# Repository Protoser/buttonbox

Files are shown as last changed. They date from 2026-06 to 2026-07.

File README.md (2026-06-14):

# Buttonbox

Custom USB button box built on an **ESP32-S3 N16R8** with a salvaged Ender 3 / CR-10 ST7920 display (128x64) and cheap mini push buttons. The device enumerates as a native USB HID gamepad and includes a companion PC app for live configuration, monitoring, media control, and button chord management.

## Build one / downloads

See the **[build guide](docs/BUILD.md)** for the bill of materials, the 3D-printed
case ([`3d_models/`](3d_models)), wiring/pinout, and assembly photos. You don't
have to compile anything — prebuilt `firmware.bin` and `ButtonboxCompanion.exe`
are on the Releases page.

## Hardware

- **MCU:** ESP32-S3 N16R8 DevKitC-1 (16 MB flash + 8 MB OPI PSRAM)
- **Display:** salvaged **Ender 3 / CR-10** "full graphic smart controller" — ST7920 128x64, software SPI
- **Buttons:** 15 cheap [mini push buttons](https://www.roboter-bausatz.de/p/schwarzer-mini-push-button) — 14 report as HID (10 always-on + 4 nav), plus 1 menu/mode toggle
- **USB:** Native TinyUSB CDC + gamepad HID

## Project structure

```
platformio.ini        PlatformIO config (ESP32-S3, Arduino framework)
src/                  ESP32 firmware source code
  main.cpp            Entry point — init in setup(), tick in loop()
  config.h            Pin map and constants
  settings.h/.cpp     NVS-persisted device settings
  buttons.h/.cpp      Debounced button input handling
  hid.h/.cpp          USB HID gamepad report generation
  chords.h/.cpp       Multi-button combos -> output keypresses
  display.h/.cpp      ST7920 LCD drawing (U8g2)
  ui.h/.cpp           On-screen menu pages, navigation and rendering
  hostlink.h/.cpp     Serial protocol: PC telemetry + config commands
  pcstats.h/.cpp      PC stats display page (CPU/RAM/GPU/temps)
  shelly.h/.cpp       Shelly smart switch integration
  stopwatch.h/.cpp    Lap timer utility

host/                 Windows companion app (Python / PySide6)
  app.py              System-tray GUI with Monitor, Device, and Chords tabs
  link.py             Background serial thread — discovery, telemetry, auto-reconnect
  sensors.py          Hardware sensor reads via psutil + LibreHardwareMonitor
  media.py            Now-playing title + media controls (Windows media session)
  secrets_store.py    Encrypted local store for the Shelly password (Windows DPAPI)
  pcstats.py          Headless CLI fallback (no GUI), streams stats only
  companion.spec      PyInstaller build spec
  build.bat           One-shot build script -> dist/ButtonboxCompanion.exe

include/              Shared project header files
lib/                  Private PlatformIO libraries
test/                 PlatformIO test runner directory
```

## Quick start — firmware

Requires [PlatformIO](https://platformio.org).

```bash
pio run -t upload    # flash to device
pio monitor          # serial console at 115200 baud
```

The build requires `espressif32` platform and the U8g2 library (pulled automatically via PlatformIO lib_deps).

## Quick start — companion app

```powershell
cd host
pip install PySide6 pyserial psutil
pip install winrt-Windows.Media.Control winrt-Windows.Foundation   # optional: Music page
pythonw app.py       # tray app (no console window)
```

Prefer not to install Python? Grab the prebuilt **`ButtonboxCompanion.exe`** from the Releases page.

### Prerequisites for full sensor support

GPU load/temp and CPU temperature require [LibreHardwareMonitor](https://github.com/LibreHardwareMonitor/LibreHardwareMonitor). Download the release zip, copy all `.dll` files into `host/`, and run the app as Administrator.

### Build standalone executable

```powershell
cd host
build.bat            # outputs dist/ButtonboxCompanion.exe
```

## Features

- **Native USB gamepad** — all 14 buttons report as HID keys, works in any game or app without drivers
- **On-screen menu** — navigate settings with the 4 multiplexed buttons and LCD display
- **Button chords** — combine 2+ physical buttons into a single output keypress (configured via PC app)
- **PC telemetry overlay** — live CPU/RAM/GPU load, temperatures, power, and VRAM displayed on the box screen
- **Music app** — shows the current track (artist / title, Cyrillic-capable) from the Windows media session and runs play/pause, next, and previous from the box (companion app required)
- **Device configuration** — rotate display, set idle blank timeout, boot screen selection, chord editing, and more — all persisted in NVS flash
- **Auto-reconnect** — companion app reconnects automatically if the USB cable is unplugged/replugged

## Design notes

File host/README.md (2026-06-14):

# Buttonbox Companion (PC app)

A system-tray app that streams PC stats to the buttonbox **and** reads/edits the
device's settings and chords live over its USB serial link. Starts minimized to
the tray and **auto-reconnects** whenever the box is unplugged/replugged.

```
host/
  app.py          the companion app (tray + Monitor / Device / Chords tabs)
  link.py         background serial thread: discovery, telemetry, commands, auto-reconnect
  sensors.py      sensor reading (psutil + LibreHardwareMonitor)
  media.py        now-playing title + transport control (Windows media session)
  pcstats.py      headless CLI fallback (no GUI), shares sensors.py
  companion.spec  PyInstaller build -> standalone .exe
  build.bat       one-shot build script
```

## Run from source

```powershell
pip install PySide6 pyserial psutil
pip install winrt-Windows.Media.Control winrt-Windows.Foundation   # Music page
python app.py            # tray app (use pythonw app.py for no console flash)
```

The two `winrt-*` packages power the **Music** page (now-playing title +
transport control) and ship prebuilt wheels (incl. Python 3.13). They're
optional — without them everything else still runs and Music just shows "Nothing
playing". (The older all-in-one `winsdk` package also works but has no 3.13
wheel, so it tries to compile from source and fails — use the `winrt-*` packages.)

It appears in the system tray (blue "BB" icon). **Left-click** the tray icon to
open the window, **right-click** for the menu (Show / Start at login / Flash
device / Quit). Closing the window hides it back to the tray.

- **Monitor** tab — connection status + live CPU/RAM/GPU/temp bars.
- **Device** tab — Rotate, grid Labels, Idle-blank, Chord window, Boot screen,
  and which PC stats the box shows. Changing any control writes it to the box and
  it persists in the box's flash. There's also a **Flash Mode** button (handy for
  firmware uploads).
- **Chords** tab — see/add/delete button chords (pick 2+ member buttons + an
  output button); changes apply on the box immediately.

The box also has a **Music** page (in its app launcher). The companion streams
the current media-session title to it and relays the box's prev / play-pause /
next button presses back to whatever is playing (Spotify, browser/YouTube, …) —
the same targets the keyboard media keys hit. Needs the `winrt-*` packages (see above).

## Temperatures (LibreHardwareMonitor)

CPU load + RAM need nothing extra. GPU load/temp and **CPU temp** need a sensor
source:

1. `pip install pythonnet`, then copy **all `.dll` files** from the
   LibreHardwareMonitor release zip into this `host/` folder
   (`LibreHardwareMonitorLib.dll` **and** its siblings `System.Memory.dll`,
   `System.Buffers.dll`, `System.Runtime.CompilerServices.Unsafe.dll`,
   `System.Numerics.Vectors.dll`, `System.Threading.Tasks.Extensions.dll`,
   `HidSharp.dll`). The app resolves them from this folder automatically.
2. **Run the app as Administrator** — CPU temperature comes from MSR/SuperIO,
   which needs the kernel sensor driver. Without admin you'll still get CPU/RAM
   and GPU load/temp, just not CPU temp.

## Build a standalone .exe

Put the LHM DLLs in `host/` first (they get bundled), then:

```powershell
build.bat            # or:  py -m PyInstaller --noconfirm companion.spec
```

Output: `dist\ButtonboxCompanion.exe` — runs without Python. Run it as admin for
temps.

## Start at login

Toggle **Start at login** in the tray menu — it adds/removes an entry under
`HKCU\…\CurrentVersion\Run` pointing at the exe (or `pythonw app.py` when run
from source), so the app launches minimized to the tray on sign-in.

## Headless fallback

`python pcstats.py` just streams stats (no GUI, no config), also auto-reconnecting.

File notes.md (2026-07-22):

## What's new since v2.3

### Clock app

- **New Clock app in the launcher** — a full-screen wall clock driven by the box's synced time (NTP over WiFi, or pushed from the PC companion; no RTC needed).
- **Analog face** inspired by a De Bethune dial: hollow **lance hands** (shaft → hollow lozenge → pointed tip) for the hour and minute, a thin sweeping second hand, and a full ring of **12 numerals** with an hour pip on the rim.
- **Digital style** as an alternative — big `HH:MM` with optional seconds and AM/PM.
- **Weekday + date** line along the bottom.
- The face uses the whole panel (no header bar) and keeps the display awake so the seconds hand keeps ticking.

### Customizing the clock

- **On the box → open Clock → Select (►)** opens a per-clock settings page. Toggle each option with Select:
  - **Style** — Analog / Digital
  - **Seconds** — show the seconds hand (or digital seconds)
  - **Numerals** — all-12 numerals vs. a plain tick ring
  - **Date** — show the weekday/date line
  - **Hour fmt** — 24h / 12h
- Settings persist across reboots.

### Fixes

- Fixed a launcher bug where adding an app could write one entry past the app-order list and corrupt adjacent settings.
- Companion app list and Boot-screen dropdown now include the **Volume** and **Clock** apps, keeping them index-aligned with the firmware.

## Install

- **Firmware:** flash `firmware.bin` to the ESP32-S3 (PlatformIO, or the on-device Flash Mode + esptool). The Clock app appears in the launcher; open it and press Select to customize.
- **Companion (Windows only):** run `ButtonboxCompanion.exe`.

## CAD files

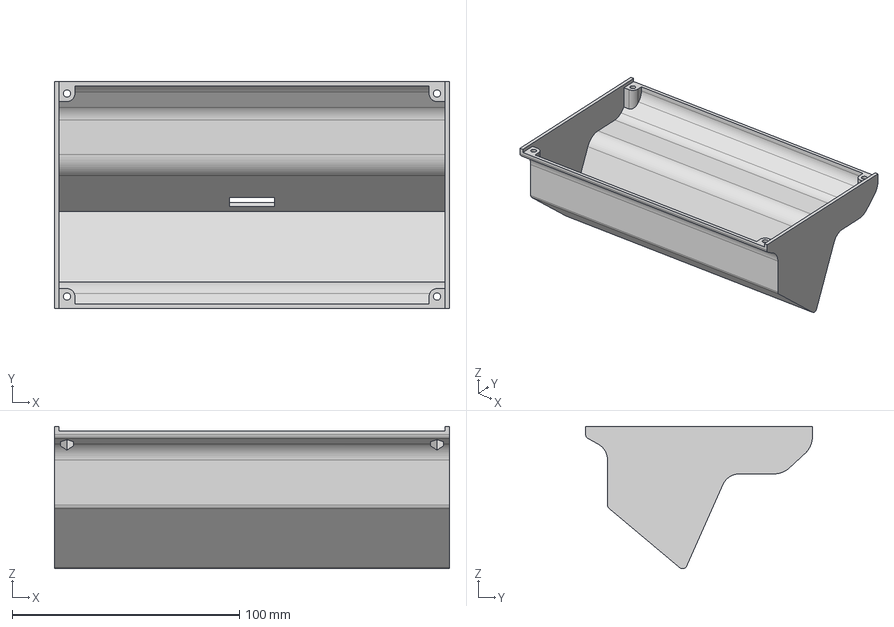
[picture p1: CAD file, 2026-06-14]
3d_models/Case.step
174.0 x 99.9 x 62.7 mm

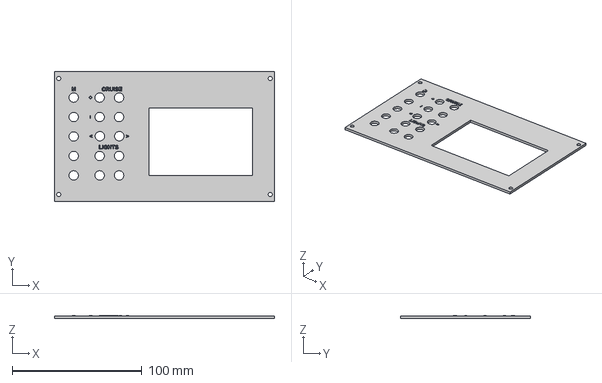
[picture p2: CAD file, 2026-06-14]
3d_models/Lid.step
169.6 x 100.0 x 2.40 mm

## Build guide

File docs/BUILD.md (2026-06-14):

# Build guide

This button box reuses the graphic LCD from an **old Ender 3 / CR‑10** (the stock
"full graphic smart controller" — a 128×64 **ST7920** panel) plus a handful of
**cheap mini push buttons**, driven by an ESP32‑S3. It enumerates as a plain USB
gamepad, so it needs no drivers, and a small Windows companion app adds live PC
stats, media control, and configuration.

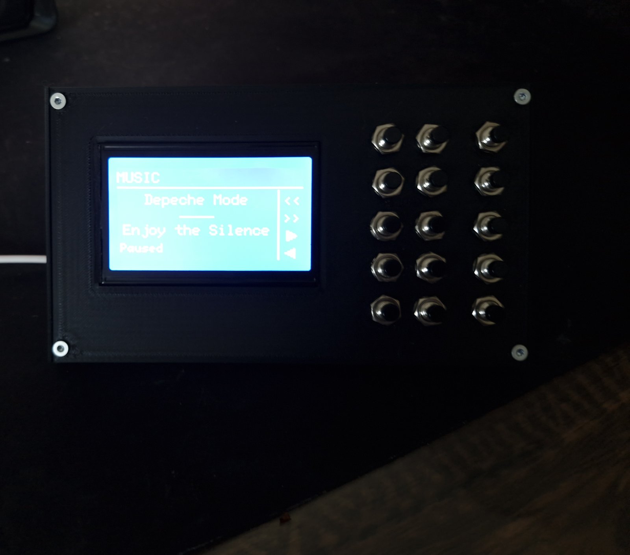
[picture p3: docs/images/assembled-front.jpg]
Assembled button box showing the Music page


## You don't have to build anything from source

Prebuilt artifacts are on the project's **Releases** page — you can skip the
toolchains entirely:

- **`firmware.bin`** — flash it straight to the ESP32‑S3 (see [Flashing](#flashing-the-firmware)).
  No PlatformIO / Arduino install needed.
- **`ButtonboxCompanion.exe`** — the Windows companion app. Just run it; no Python needed.

Building from source is only necessary if you want to change the firmware or the app.

## Bill of materials

| Qty | Part | Notes |
|----:|---|---|
| 1 | ESP32‑S3 **N16R8 DevKitC‑1** | 16 MB flash / 8 MB PSRAM. Any ESP32‑S3 devkit with native USB works. |
| 1 | 128×64 **ST7920** "12864" graphic LCD | The **Ender 3 / CR‑10 stock display** (RepRapDiscount full graphic smart controller). Salvage one, or buy a 12864 module. |
| 15 | Mini push buttons | e.g. [roboter‑bausatz mini push button](https://www.roboter-bausatz.de/p/schwarzer-mini-push-button). |
| — | Hook‑up / Dupont wire | For the button and display wiring. |
| 1 | USB‑C cable (data) | To the ESP32‑S3. |
| 4 | M3 screws | Hold the lid to the case (corners). |
| — | 3D‑printed **Case** + **Lid** | See below. |

The 15 buttons break down as **10 main** + **4 nav** + **1 menu/mode** button.

> **ESP32-S3 board notes:**
> - Use the port labeled **USB** (the native USB), **not COM** (the UART bridge) — the
>   box only enumerates as a USB gamepad over the native USB port.
> - On **clone** boards, bridge the **IN-OUT** solder pads so the USB port's 5V is
>   routed to the board's **5V** pin — that's what powers the screen. (Genuine
>   Espressif boards already have this connected.)

## 3D‑printed parts

STEP files are in [`3d_models/`](../3d_models):

- [Case.step](../3d_models/Case.step) — the body that covers the wiring
- [Lid.step](../3d_models/Lid.step) — the front cover containing the screen and buttons

### Two mounting orientations

The box works **either way up** — display‑left / buttons‑right, or
display‑right / buttons‑left — so you can mount it to suit your desk. The
firmware's **Rotate** setting flips the screen 180° *and* moves the on‑screen
button hints to the matching side. Set it once to match how you mounted it:

- on‑device: **Menu → Settings → Rotate**, or
- in the companion's **Device** tab → *Rotate*.

### Removing the embossed text

The part has text embossed on it. To print without it, remove it in your slicer:
import the STEP, **split it into parts/objects**, select the **text body**, and
delete it before slicing.

- PrusaSlicer / Bambu Studio / OrcaSlicer: right‑click the object → *Split to objects/parts*
- Cura: *Split model into parts*

The rest of the part is unaffected.

## Preparing the salvaged screen

These 12864 panels come as a full controller board with a **rotary encoder**, a
**buzzer/speaker** (the "BELL +" pad visible in the soldered photo), an SD slot and
a reset button. This build uses only the LCD, so **desolder the rotary encoder and
the buzzer** — they're unused and the encoder sticks out the front, so removing it
lets the panel sit flush in the lid.

I went the separate‑push‑button route on purpose: the encoder on my salvaged
screen was **dead**, and that's common — these displays often sit in a drawer for
years after a printer upgrade, and the encoder (or its solder joints / contacts)
degrades. Driving the ST7920 LCD directly and adding cheap new buttons sidesteps a
part that's likely broken anyway.

## Wiring / pinout

Every button is wired the same trivial way: **one leg to a GPIO, the other leg to
GND**. The firmware enables the ESP32's internal pull‑ups, so **no resistors are
needed**. All the button grounds can share a single daisy‑chained GND wire (see
the soldered photo below).

### Display (ST7920, software SPI)

| ESP32‑S3 | Display pin |
|---|---|
| GPIO **17** | **Clock** (ST7920 E) |
| GPIO **18** | **Data** (ST7920 R/W / MOSI) |
| GPIO **21** | **Chip Select** (ST7920 RS) |
| **5V** | **5V** |
| **GND** | **Ground** |

On the Ender 3 / CR‑10 12864 these signals come out on the **EXP3** ribbon and the
panel PCB is labeled (E / RW / RS). It runs in ST7920 *serial* mode (the PSB pin
tied low — already handled on the RepRapDiscount board).

The diagram below — an **ST7920-based Ender 3 display** (EXP3 connector) — labels
the lines by function, which makes wiring obvious:

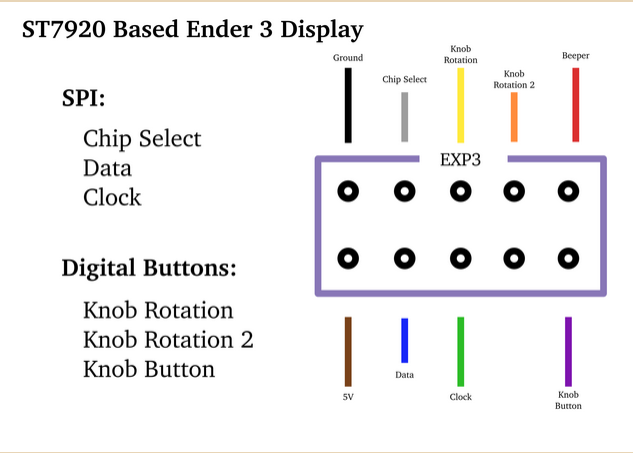
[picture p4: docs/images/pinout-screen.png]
ST7920-based Ender 3 display: EXP3 connector pinout


Connect **Ground** and **5V** to the ESP's GND/5V, and the three SPI lines to the
GPIOs in the table above: **Clock -> GPIO 17**, **Data -> GPIO 18**,
**Chip Select -> GPIO 21**. The remaining pins (Knob Rotation x2, Knob Button,
Beeper) drove the original encoder and buzzer and aren't used here.

*Connector pinout diagram from [maddie.info](https://maddie.info/hardware/2023/07/01/ender3-exp3-pinout.html).*

### Buttons

| ESP32‑S3 GPIO | Role |
|---|---|
| **2** | Menu / Mode button (not a HID button) |
| **1** | Nav — Up |
| **5** | Nav — Down |
| **6** | Nav — Select |
| **4** | Nav — Back |
| **7, 8, 9, 10, 11, 12, 13, 14, 15, 16** | Main HID buttons 1–10 |

The 4 nav buttons double as HID buttons 11–14 in normal mode; the **menu/mode**
button switches those four between gamepad buttons and on‑screen menu navigation.
The full pin map lives in [`src/config.h`](../src/config.h) if you want to rewire.

## Assembly

| Jumpered (test first) | Soldered (tidy) |
|---|---|
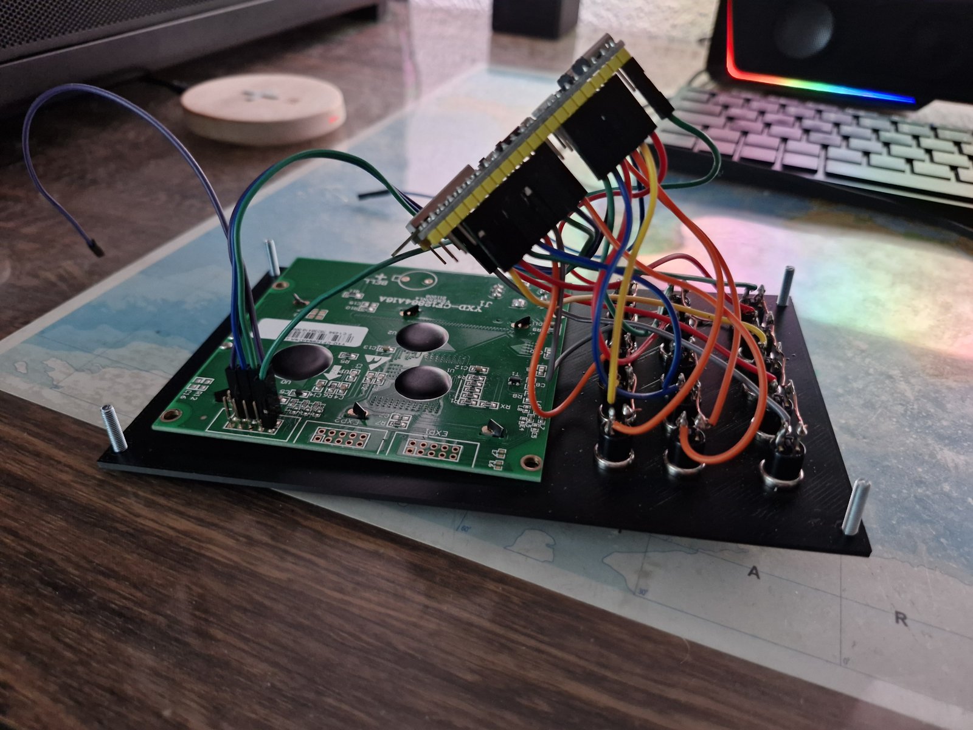
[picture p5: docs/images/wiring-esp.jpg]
ESP wired to buttons and display
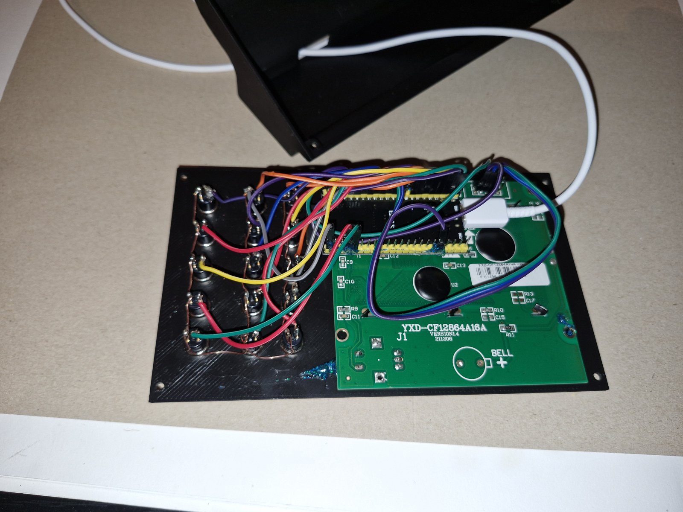
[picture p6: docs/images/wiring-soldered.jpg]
Buttons soldered with a shared ground chain
|  |  |

1. Print both parts (remove the embossed text first if you want it gone).
2. Desolder the encoder + buzzer from the screen (see above), then mount the 15 push buttons and the LCD into the **Lid** (the front).
3. Wire each button: signal leg → its GPIO (table above), other leg → the shared GND chain.
4. Wire the display's five lines to the ESP (table above).
5. Set the ESP into the **Case** (the back body), join it to the Lid, screw the corners, and plug in USB.

Tip: build the messy jumper‑wire version first and confirm every button and the
screen work, *then* solder it tidy.

## Flashing the firmware

**Prebuilt (recommended):** download `firmware.bin` (a full, merged flash image)
from the Releases page and write it at offset **0x0**:

- Browser flasher — open <https://espressif.github.io/esptool-js/>, connect, set
  offset `0x0`, choose `firmware.bin`, **Program**.
- Or esptool — `esptool --chip esp32s3 write_flash 0x0 firmware.bin`

To put a running box into download mode: use the companion's **Flash Mode** button,
or hold **BOOT** on the devkit while tapping **RESET**, then release BOOT.

**From source:** with [PlatformIO](https://platformio.org) installed, `pio run -t upload`
(see the main [README](../README.md)).

## Companion app (optional)

The Windows companion streams PC stats to the box, drives the **Music** page
(now‑playing title + transport control), and edits the box's settings and chords
live. Use the prebuilt `ButtonboxCompanion.exe`, or run it from source — see
[`host/README.md`](../host/README.md).

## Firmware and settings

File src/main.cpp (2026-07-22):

// ============================================================================
//  ESP32-S3 buttonbox  —  15 buttons + CR-10 (ST7920) display
//
//  Native NKRO USB HID keyboard + an on-screen menu UI. Modules:
//    config    pin map / counts            buttons   debounced inputs
//    display   the ST7920 panel            hid       key output dispatch
//    settings  NVS-persisted options       keyboard  NKRO USB keyboard
//    chords    2+ button combos -> output  ui        pages / nav / rendering
//  This file just wires them together: init in setup(), tick in loop().
// ============================================================================

#include <Arduino.h>
#include "soc/soc.h"            // REG_CLR_BIT
#include "soc/rtc_cntl_reg.h"   // RTC_CNTL_OPTION1_REG, RTC_CNTL_FORCE_DOWNLOAD_BOOT
#include "settings.h"
#include "buttons.h"
#include "hid.h"
#include "chords.h"
#include "hostlink.h"
#include "shelly.h"
#include "wled.h"
#include "clock.h"
#include "ui.h"

#if !defined(ARDUINO_USB_MODE) || ARDUINO_USB_MODE != 0
#error "Set -DARDUINO_USB_MODE=0 in platformio.ini so the box enumerates as a native USB keyboard."
#endif

void setup() {
  // Clear the force-download flag so a normal reset never re-enters flash mode.
  REG_CLR_BIT(RTC_CNTL_OPTION1_REG, RTC_CNTL_FORCE_DOWNLOAD_BOOT);

  loadSettings();
  chordsLoad();
  shellyBegin();
  wledBegin();
  clockBegin();
  uiBegin();
  // buttonsBegin() runs AFTER uiBegin() on purpose: displayBegin() brings up hardware
  // SPI, whose ESP32 init grabs the bus's default MISO pad (GPIO 13) — which is HID
  // button 7. Claiming the button pins last re-owns GPIO 13 as INPUT_PULLUP so it
  // stops floating and machine-gunning phantom presses. See display.cpp.
  buttonsBegin();
  hidBegin();
  Serial.begin(115200);
  uiNoteActivity(millis());
}

void loop() {
  uint32_t now = millis();

  buttonsUpdate(now);
  hostlinkUpdate(now);            // drain serial: PC telemetry + config commands
  clockUpdate(now);               // bring up NTP once WiFi is associated
  if (buttonsAnyEdge())         uiNoteActivity(now);
  uiHandleMenuButton(now);        // tap = launcher/resume, hold = quick-switch app

  // The brightness overlay (opened by a chord) is modal: while it's up it owns the
  // nav buttons on whatever page is showing, so it runs before normal page input.
  if (!uiHandleBrightness(now)) {
    // On non-Buttons pages the UI first claims the buttons it needs (the nav
    // buttons, or all buttons on the capture/test pages) by suppressing them.
    if (uiPage() != PAGE_BUTTONS) uiHandlePageInput();
  }
  // The chord/HID engine then runs on EVERY page: any button not claimed by the
  // UI stays a live key (so the non-nav buttons work everywhere).
  updateChords(now);

  if (uiPage() == PAGE_TIMER)   uiHandleTimerLap(now);
  uiTickCountdown(now);            // countdown timer: expiry pop-up (any page) + hold gestures
  uiHandleWledBright(now);         // self-gating; handles hold-to-scroll + release flush
  // The display renders on its own task pinned to core 0 (started in uiBegin) so the
  // slow ST7920 flush never blocks button sampling here on core 1.
}

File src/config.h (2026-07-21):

#pragma once
#include <Arduino.h>

// ============================================================================
//  Pin map  —  ESP32-S3 N16R8 DevKitC-1
//  Avoided: 19/20 (native USB), 26-32 (flash), 33-37 (octal PSRAM),
//           0/3/45/46 (strapping).
// ============================================================================

// ---- CR-10 display (ST7920 128x64, software SPI) ----
static const uint8_t LCD_CLOCK_PIN = 17;  // ST7920 E   (clock)
static const uint8_t LCD_DATA_PIN  = 18;  // ST7920 R/W (data / MOSI)
static const uint8_t LCD_CS_PIN    = 21;  // ST7920 RS  (chip select)

// ---- Backlight dimming ----
// GPIO -> series resistor -> backlight LED. Driven by LEDC PWM (see display.cpp);
// duty sets brightness. Low current, so no MOSFET — the pin sinks/sources it direct.
static const uint8_t LCD_BACKLIGHT_PIN = 38;

// ---- Mode toggle ("menu" button) ----
// The cluster button wired to GPIO 2 (the one you use as the menu button).
// Switches the 4 nav buttons between HID buttons (NORMAL) and on-screen
// menu navigation (MENU). It is NOT reported as a HID button itself.
static const uint8_t MODE_TOGGLE_PIN = 2;

// ---- Always-on HID buttons ----
// Each wires GPIO -> button -> GND (internal pull-ups, no resistors needed).
// The 10 non-cluster buttons; no special function, numbering doesn't matter.
// HID button index is assigned in array order, starting at 0.
static const uint8_t ALWAYS_BUTTON_PINS[] = {7, 8, 9, 10, 11, 12, 13, 14, 15, 16};

// ---- The 4 menu/nav buttons ----
// The other four cluster buttons, listed physical TOP -> BOTTOM.
// NORMAL mode: HID buttons (indices continue after the always-on set: 10..13).
// MENU mode:   UP, DOWN, SELECT, BACK  (in this order — rearrange to taste).
static const uint8_t NAV_BUTTON_PINS[] = {1, 5, 6, 4};

static constexpr uint8_t NUM_ALWAYS = sizeof(ALWAYS_BUTTON_PINS) / sizeof(ALWAYS_BUTTON_PINS[0]);
static constexpr uint8_t NUM_NAV    = sizeof(NAV_BUTTON_PINS)    / sizeof(NAV_BUTTON_PINS[0]);
static constexpr uint8_t NUM_HID    = NUM_ALWAYS + NUM_NAV;   // 14 physical buttons

// Menu navigation actions, in NAV_BUTTON_PINS order.
enum NavAction : uint8_t { NAV_UP = 0, NAV_DOWN = 1, NAV_SELECT = 2, NAV_BACK = 3 };

// Lockout debounce window (see buttons.cpp): a press registers the instant the
// contact closes, then any further edge is ignored for this long. So it both
// catches a short click and collapses contact bounce / rapid retriggers into one
// press. Set it a bit above the switch's worst-case bounce (~10-20 ms for cheap
// tactile/arcade buttons). It's also the minimum gap between two distinct presses.
static const uint16_t DEBOUNCE_MS = 50;

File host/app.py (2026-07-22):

"""Buttonbox companion — system-tray app that streams PC stats to the box and
reads/edits its settings and chords live. Starts minimized to the tray.

The window is a left-sidebar settings app: a short list of focused panes
(Monitor / Display / Apps / Chords / Network / Device) rather than a few
overloaded tabs, so each screen stays small and single-purpose. A persistent
header shows the connection state from every pane.

Run:   python app.py        (or pythonw app.py for no console)
"""
import os
import sys

from PySide6.QtCore import Qt, QTimer, QUrl, Signal
from PySide6.QtGui import QAction, QColor, QFont, QIcon, QPainter, QPalette, QPixmap
from PySide6.QtWebSockets import QWebSocket
from PySide6.QtWidgets import (
    QApplication, QCheckBox, QComboBox, QFormLayout, QFrame, QGridLayout, QGroupBox,
    QHBoxLayout, QLabel, QLineEdit, QListWidget, QListWidgetItem, QMainWindow, QMenu,
    QProgressBar, QPushButton, QScrollArea, QStackedWidget, QSystemTrayIcon, QTabWidget,
    QVBoxLayout, QWidget,
)

import mcdu as mcdu_mod
import secrets_store
from link import DeviceLink

MCDU_WS_URL = "ws://localhost:8380/interfaces/v1/mcdu"   # FlyByWire SimBridge remote MCDU

# ---- constants mirrored from the firmware (config.h / settings) ----
NUM_HID = 14            # physical buttons, shown 1..14
OUT_MIN, OUT_MAX = 14, 31     # chord outputs (shown 15..32)
OUT_BRIGHT = 32         # special chord output: open the backlight-brightness overlay (mirror chords.h CHORD_OUT_BRIGHT)
OUT_VOLUME = 33         # special chord output: open the volume mixer page (mirror chords.h CHORD_OUT_VOLUME)
TOGGLE_BIT = NUM_HID    # chord-member bit for the menu/toggle button (mirror chords.h CHORD_MEMBER_TOGGLE)
MAX_CHORDS = 18
IDLE_OPTS  = [(0, "Off"), (30, "30 s"), (120, "2 min")]
CHORD_OPTS = [30, 40, 60, 80]
BRIGHT_OPTS  = [(v, f"{v}%") for v in (10, 25, 40, 55, 70, 85, 100)]   # normal backlight brightness
IDLEBR_OPTS  = [(0, "Off"), (10, "10%"), (20, "20%"), (40, "40%")]     # dimmed backlight brightness
DIM_OPTS     = [(0, "Off"), (10, "10 s"), (30, "30 s"), (60, "60 s")]  # auto-dim delay
BOOT_OPTS  = [(0, "Apps launcher"), (1, "Buttons"), (2, "Stopwatch"), (3, "PC"), (4, "Shelly"),
              (5, "Music"), (6, "Menu"), (7, "WLED"), (8, "BeamNG"), (9, "Flight"), (10, "MCDU"),
              (11, "Timer"), (12, "Volume"), (13, "Clock")]
APP_NAMES  = ["Buttons", "Stopwatch", "PC", "Shelly", "Music", "Menu", "WLED", "BeamNG", "Flight",
              "MCDU", "Timer", "Volume", "Clock"]  # mirror ui.cpp APPS index order
MENU_APP   = APP_NAMES.index("Menu")   # never hideable
PCSTAT_BITS = [("CPU", 0), ("RAM", 1), ("GPU", 2), ("CPU Temp", 3), ("GPU Temp", 4),
               ("VRAM", 5), ("CPU Power", 6), ("GPU Power", 7)]
PCSTAT_MAX = 5      # box shows up to 5 at once
# (wire key, label, unit, bar min, bar max)
STAT_ROWS = [("cpu", "CPU", "%",   0, 100), ("ram", "RAM", "%",   0, 100), ("gpu", "GPU", "%", 0, 100),
             ("ct", "CPU Temp", "°C", 30, 100), ("gt", "GPU Temp", "°C", 30, 100),
             ("vr", "VRAM", "%", 0, 100), ("cp", "CPU Power", "W", 0, 250), ("gp", "GPU Power", "W", 0, 450)]

# Keyboard bindings (Keys pane). Each output (0..13 physical, 14..31 chord outputs) maps to a
# modifier mask + one HID usage (Keyboard/Keypad page 0x07; 0 = unbound). F13–F24 lead the list:
# phantom keys no real keyboard has, so they never collide with typing/shortcuts.
MODS = [("Ctrl", 0x01), ("Shift", 0x02), ("Alt", 0x04), ("Win", 0x08)]
KEY_CHOICES = (
    [("—", 0x00)]
    + [(f"F{n}", 0x68 + n - 13) for n in range(13, 25)]                       # F13..F24 = 0x68..0x73
    + [(f"F{n}", 0x3A + n - 1) for n in range(1, 13)]                         # F1..F12  = 0x3A..0x45
    + [(chr(ord("A") + i), 0x04 + i) for i in range(26)]                      # A..Z     = 0x04..0x1D
    + [(str((i + 1) % 10), 0x1E + i) for i in range(10)]                      # 1..9,0   = 0x1E..0x27
    + [("Enter", 0x28), ("Esc", 0x29), ("Backspace", 0x2A), ("Tab", 0x2B), ("Space", 0x2C),
       ("- _", 0x2D), ("= +", 0x2E), ("[ {", 0x2F), ("] }", 0x30), ("\\ |", 0x31),
       ("; :", 0x33), ("' \"", 0x34), ("` ~", 0x35), (", <", 0x36), (". >", 0x37), ("/ ?", 0x38),
       ("PrtSc", 0x46), ("ScrLk", 0x47), ("Pause", 0x48),
       ("Insert", 0x49), ("Home", 0x4A), ("PgUp", 0x4B), ("Delete", 0x4C), ("End", 0x4D), ("PgDn", 0x4E),
       ("Right", 0x4F), ("Left", 0x50), ("Down", 0x51), ("Up", 0x52)]
)
USAGE_LABEL = {usage: label for label, usage in KEY_CHOICES}

# Windows virtual-key code -> HID usage, for the press-to-set key capture
# (the companion is Windows-only, so nativeVirtualKey() is always a VK code).
VK_TO_HID = {}
for _i in range(26):                                   # A..Z
    VK_TO_HID[0x41 + _i] = 0x04 + _i
for _i in range(9):                                    # 1..9
    VK_TO_HID[0x31 + _i] = 0x1E + _i
VK_TO_HID[0x30] = 0x27                                 # 0
for _i in range(12):                                   # F1..F12
    VK_TO_HID[0x70 + _i] = 0x3A + _i
for _i in range(12):                                   # F13..F24 (some keyboards/macros send them)
    VK_TO_HID[0x7C + _i] = 0x68 + _i
VK_TO_HID.update({
    0x0D: 0x28, 0x1B: 0x29, 0x08: 0x2A, 0x09: 0x2B, 0x20: 0x2C,   # Enter Esc BS Tab Space
    0xBD: 0x2D, 0xBB: 0x2E, 0xDB: 0x2F, 0xDD: 0x30, 0xDC: 0x31,   # -  =  [  ]  Backslash
    0xBA: 0x33, 0xDE: 0x34, 0xC0: 0x35, 0xBC: 0x36, 0xBE: 0x37, 0xBF: 0x38,  # ; ' ` , . /
    0x2C: 0x46, 0x91: 0x47, 0x13: 0x48,                            # PrtSc ScrLk Pause
    0x2D: 0x49, 0x24: 0x4A, 0x21: 0x4B, 0x2E: 0x4C, 0x23: 0x4D, 0x22: 0x4E,  # Ins Home PgUp Del End PgDn
    0x27: 0x4F, 0x25: 0x50, 0x28: 0x51, 0x26: 0x52,                # Right Left Down Up
})

APP_NAME = "ButtonboxCompanion"
RUN_KEY = r"Software\Microsoft\Windows\CurrentVersion\Run"


# ---------------------------------------------------------------- autostart ----
def _autostart_target():
    if getattr(sys, "frozen", False):
        return f'"{sys.executable}"'
    pyw = os.path.join(os.path.dirname(sys.executable), "pythonw.exe")
    return f'"{pyw}" "{os.path.abspath(__file__)}"'


def is_autostart():
    try:
        import winreg
        with winreg.OpenKey(winreg.HKEY_CURRENT_USER, RUN_KEY) as k:
            winreg.QueryValueEx(k, APP_NAME)
            return True
    except Exception:        # noqa: BLE001
        return False


def set_autostart(enable):
    import winreg
    with winreg.OpenKey(winreg.HKEY_CURRENT_USER, RUN_KEY, 0, winreg.KEY_SET_VALUE) as k:
        if enable:
            winreg.SetValueEx(k, APP_NAME, 0, winreg.REG_SZ, _autostart_target())
        else:
            try:
                winreg.DeleteValue(k, APP_NAME)
            except FileNotFoundError:
                pass
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

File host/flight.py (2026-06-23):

"""Microsoft Flight Simulator telemetry via SimConnect.

Reads live instruments from MSFS (2020/2024; also FSX/P3D) using the `SimConnect`
Python package (`pip install SimConnect`), which bundles SimConnect.dll and talks
to the running sim. `Listener` owns the connection: `open()` connects (False if the
sim isn't running, so the caller retries), `read_latest()` polls the simvars and
returns the compact dict the box's `flight` serial line carries, `close()` drops
the link. If the package is missing the module degrades gracefully: `available()`
is False and the producer stays idle, exactly like media.py without WinRT.

Unit notes (SimConnect native units, converted here to what the box expects):
  - headings come back in RADIANS -> degrees
  - vertical speed uses VELOCITY_WORLD_Y (feet/second) -> feet/minute
  - gear/flaps/spoilers/throttle are percent (0..100)
Verify these against the sim during bring-up (see the plan's verification steps);
if a value reads wildly off, the unit assumption for that simvar is the suspect.
"""
import math

try:
    from SimConnect import SimConnect, AircraftRequests
    _OK = True
    # Quiet the library's own logger so a broken pipe (MSFS closed) doesn't spam the
    # console from its receiver thread. Harmless if the library doesn't use logging.
    import logging
    logging.getLogger("SimConnect").setLevel(logging.CRITICAL)
except Exception:                       # noqa: BLE001 — package absent or not on Windows
    _OK = False

# ENGINE_TYPE simvar -> the box's etyp (0 piston, 1 jet, 2 turboprop).
# SimConnect: 0 piston, 1 jet, 2 none, 3 helo-turbine, 4 unsupported, 5 turboprop.
_ENG_TYPE = {0: 0, 1: 1, 5: 2}


def available() -> bool:
    """True if SimConnect can be used (the package imported)."""
    return _OK


def _num(v, default=0.0):
    """SimConnect returns None while the sim is on a loading screen (and for any
    var name it doesn't know); coerce that (and any non-numeric) to a default so
    one missing var doesn't sink the whole line."""
    try:
        return float(v)
    except (TypeError, ValueError):
        return default


def _pct(v):
    """A 0..100 percentage. SimConnect's "percent over 100" vars come back as a
    0..1 fraction in some library versions and 0..100 in others; accept either."""
    x = _num(v)
    if 0.0 < x <= 1.0:                   # fraction -> percent
        x *= 100.0
    return max(0, min(100, int(round(x))))


class Listener:
    """An open SimConnect link that yields the latest instrument snapshot."""

    def __init__(self):
        self._sm = None
        self._aq = None

    def open(self) -> bool:
        """Connect to the running sim. Returns False if MSFS isn't up (the
        SimConnect() constructor raises), so the caller can retry later."""
        if not _OK:
            return False
        try:
            self._sm = SimConnect()
            # _time caches each var for N ms so repeated gets in one read are cheap.
            self._aq = AircraftRequests(self._sm, _time=200)
            return True
        except Exception:               # noqa: BLE001 — sim not running / SDK missing
            self.close()
            return False

    def close(self):
        sm = self._sm
        self._sm = None                 # drop refs first so a concurrent read bails
        self._aq = None
        if sm is not None:
            try:
                sm.quit = 1             # stop the library's receiver thread promptly
            except Exception:           # noqa: BLE001
                pass
            try:
                sm.exit()
            except Exception:           # noqa: BLE001 — pipe already broken
                pass

    def read_latest(self) -> dict | None:
        """Poll the simvars and return the box's field set, or None if the link
        died (caller reopens). A fresh-but-not-ready sim returns zeros, not None."""
        aq, sm = self._aq, self._sm
        if aq is None or sm is None:
            return None
        if getattr(sm, "quit", 0):       # sim sent QUIT (MSFS closed) -> drop the link
            return None
        try:
            g = aq.get
            # Heading & AP heading select come back in radians; AP alt/hdg-dir vary,
            # so normalize all angles through degrees().
            hdg = int(round(math.degrees(_num(g("PLANE_HEADING_DEGREES_MAGNETIC"))))) % 360
            vs  = int(round(_num(g("VELOCITY_WORLD_Y")) * 60.0))   # ft/s -> ft/min
            # SimConnect sign convention: pitch + = nose DOWN, bank + = roll LEFT.
            # The box wants pitch + = nose UP and bank + = roll RIGHT, so negate both.
            pit = max(-90, min(90, -int(round(math.degrees(_num(g("PLANE_PITCH_DEGREES")))))))
            bnk = max(-90, min(90, -int(round(math.degrees(_num(g("PLANE_BANK_DEGREES")))))))

            modes = 0
            if _num(g("AUTOPILOT_HEADING_LOCK")):  modes |= 0x01   # AP_HDG
            if _num(g("AUTOPILOT_ALTITUDE_LOCK")): modes |= 0x02   # AP_ALT
            if _num(g("AUTOPILOT_NAV1_LOCK")):     modes |= 0x04   # AP_NAV
            if _num(g("AUTOPILOT_APPROACH_HOLD")): modes |= 0x08   # AP_APR

            etyp = _ENG_TYPE.get(int(_num(g("ENGINE_TYPE"))), 0)
            neng = max(1, min(4, int(_num(g("NUMBER_OF_ENGINES"), 1))))

            def _engval(i):                                        # per-engine gauge
                if etyp == 1:                                      # jet: N1 % -> x10
                    return max(0, int(round(_num(g(f"TURB_ENG_N1:{i}")) * 10)))
                return max(0, int(round(_num(g(f"GENERAL_ENG_RPM:{i}")))))  # RPM
            eng1, eng2, eng3, eng4 = _engval(1), _engval(2), _engval(3), _engval(4)

            cap = _num(g("FUEL_TOTAL_CAPACITY"))
            fuel = int(round(_num(g("FUEL_TOTAL_QUANTITY")) / cap * 100)) if cap > 0 else 0
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

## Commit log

2026-06-10 fixed bugs from the first version
    [app.py, hostlink.cpp, link.py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]
2026-06-14 Added docs
    [Case.step, Lid.step]
2026-06-17 Redesign companion UI as a left-sidebar settings app
    Replace the three-tab layout (Monitor/Device/Chords) -- whose Device tab crammed five unrelated concerns into one overflowing form -- with a left-sidebar nav over six focused panes: Monitor, Display, Apps, Chords, Network, Device. Move the chord-window setting into Chords, surface autostart in the Device pane (synced with the tray), and add a persistent connection header. The sidebar is palette-driven so it matches the system theme instead of a hard-coded light slab.
    Host-only change; serial protocol and firmware unchanged.
    [app.py]
2026-06-18 Music page: reset title scroll on song change with a 5s read pause
    Anchor the scroll to when the title last changed instead of free-running
    millis(): hold the title at its start for 5s (readable), then scroll one
    glyph/sec and loop. A new song now appears from the beginning.
    [ui.cpp]
2026-06-22 Fix unresponsive fast button presses
    Two independent causes of dropped quick taps:
    - Chord members deferred their solo HID press until the chord window
    elapsed, so a tap shorter than the window was swallowed entirely. Now
    a member released inside the window without forming a chord fires as a
    quick tap, and every solo press is held a minimum time so brief taps
    survive USB polling.
    - The slow ST7920 software-SPI flush ran in loop(), blocking button
    sampling for tens of ms per frame; a tap landing inside a redraw was
    never sampled. Move rendering to a dedicated task pinned to core 0 so
    the core-1 input/HID loop never blocks on the display. The render task
    is the sole panel own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
    [main.cpp, ui.cpp]
2026-07-09 Add dimmable backlight: brightness levels, idle auto-dim, chord overlay
    PWM-drive the display backlight on GPIO 38 (LEDC, 20 kHz) with a
    gamma-corrected mapping. Two persisted levels (active + idle) plus an
    auto-dim delay; the screen dims to the idle level after inactivity and
    restores on any press. Adjustable on-device (Settings), from the
    companion app (Display pane), or on the fly via a chord that pops a
    brightness overlay (reserved chord output 32, works on any page).
    [app.py, config.h, display.cpp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]
2026-07-09 Brightness overlay: single-flush render so the bar doesn't blink
    While the overlay is up, composite it over the retained framebuffer and
    flush once instead of redrawing (flushing) the page first and the overlay
    second, which made the bar flicker off every heartbeat on the slow ST7920.
    [ui.cpp]
2026-07-14 Add volume mixer + let the menu button be a chord member
    Volume mixer: a chord (special output 33) opens a Volume page listing the
    Windows master + per-app levels; Up/Down move the cursor, Select enters
    adjust mode, Up/Down change the level. The companion streams state and
    applies changes via pycaw (volume_audio.py); absent pycaw the page shows
    "No companion". Also selectable from the launcher.
    Menu-as-chord: the dedicated menu/toggle button can now be a chord member
    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
2026-07-14 Menu chords: don't let hold-to-quick-switch pre-empt a menu chord
    When the menu button is a chord member, holding it (to then press the other
    member) fired the 400ms hold-to-quick-switch before the chord could form, so
    menu chords only worked if pressed near-simultaneously. Suppress the menu
    hold action whenever the menu button is a member of any configured chord.
2026-07-14 Menu chords: let Menu+nav chords form on pages that claim nav buttons
    uiHandlePageInput claimed (suppressed) every nav press on non-Buttons pages
    before the chord engine ran, so a chord pairing the menu button with a nav
    button could never form anywhere but the Buttons page. While the menu button
    is held, buttons that appear in a chord with it are now left to the chord
    engine (except on capture, where menu is the save key). Same guard for the
    Timer lap button, which reads its nav button directly.
2026-07-15 Volume: discard mixer snapshots made stale by a box change mid-read
    The echo fix updated the cache on volset, but _volume_loop could already be
    inside mixer.read() when the change arrived; its pre-change snapshot then
    overwrote the cache and the box's level visibly snapped back for one stream
    tick (95 -> 100 -> 95). Track a generation counter bumped per box change and
    drop any snapshot whose read straddled a bump.
    [link.py]
2026-07-15 Menu chords: hold menu alone 500 ms still quick-switches apps
    Instead of disabling hold-to-quick-switch entirely when the menu button is a
    chord member, raise its threshold to 500 ms: a chord partner pressed inside
    that window forms the chord first, while a solo hold past it still switches
    to the previous app.
2026-07-15 Flash Mode: keep the backlight lit through the reboot into the bootloader
    Since the backlight became PWM-driven, rebooting into the ROM bootloader
    stopped the LEDC output and left the pin floating, so the "run upload now"
    prompt went dark mid-flash. Drive the pin solid high and latch it with the
    RTC-domain pad hold (survives the software reset); displayBegin() releases
    the hold on the next boot before re-attaching the PWM.
    [display.cpp, ui.cpp]
2026-07-21 Flash Mode backlight: clear the force-unhold gate so the pad hold engages
    gpio_hold_en's per-pad bit is gated by RTC_CNTL_DG_PAD_FORCE_UNHOLD, which
    defaults to 1 — the hold silently did nothing and the backlight pin still
    floated in the bootloader. Clear the gate when latching the pin.
2026-07-21 Keys pane: press-to-set key capture replaces the key dropdown
    Click a row's key field and press the shortcut on the real keyboard - the
    key and its held modifiers are captured together (VK -> HID usage mapping).
    Esc cancels a capture; right-click offers Clear and the phantom F13-F24
    keys a real keyboard can't type. Preset/load paths now set the button
    instead of a combo index.
    [app.py]
2026-07-21 Keyboard macro mode: NKRO keyboard output with per-output key bindings
    The box now enumerates as an NKRO USB keyboard instead of a 32-button gamepad. Each output (14 physical + 18 chord) binds to a HID key + modifiers, editable from the companion Keys pane and on-device (Menu > Key Binds). Adds keyboard.* (NKRO device), a hid.* output-dispatch layer, keymap persistence, and the kb/nkeys/set-keybind protocol. Also: header clock shows seconds (from clock.cpp); shortened long page titles so they clear the wider clock.
    [config.h, hostlink.cpp]
2026-07-22 Clock app: analog (De Bethune-style) / digital face with a settings page
    Adds a Clock launcher app driven by the existing synced clock (NTP / PC).
    The analog face uses hollow lance hands and a full ring of 12 numerals; a
    digital style shows big HH:MM. A per-clock settings page (Select on the app)
    toggles style, seconds, numerals, date, and 12/24h, persisted via clockFlags.
    Full-screen (no header); keeps the display awake so the seconds hand ticks.
    Also fixes a launcher out-of-bounds: APP_ORDER_MAX was still 12 while the new
    app made APP_COUNT 13, so the App Order page wrote one past settings.appOrder.
    Host app.py APP_NAMES/BOOT_OPTS updated for Volume (pre-existing gap) and Clock.
    Co-Autho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
    [app.py, settings.cpp, settings.h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]
2026-07-22 Display: hardware SPI + dithered gray pipeline, applied to Clock/PFD/App Order
    - Move the ST7920 from bit-banged software SPI to hardware SPI for a much
    faster flush (pinned at 1 MHz, the panel's reliable ceiling over the CR-10
    ribbon). Claim the bus with MISO=-1 and init buttons after the display so the
    SPI setup never steals GPIO 13 (HID button 7).
    - Add a shared fake-gray pipeline (grayOn/grayLine/grayFillRect) for the 1-bit
    panel: flip/rand/bayer dither modes. Pages that paint temporal gray free-run
    automatically so 50% flip stays flicker-free.
    - New Debug page (Menu -> Debug) to tune dither method/duty and the SPI clock live.
    - Clock: textured 20% noise dial background and a s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
    [display.cpp, main.cpp, ui.cpp]
